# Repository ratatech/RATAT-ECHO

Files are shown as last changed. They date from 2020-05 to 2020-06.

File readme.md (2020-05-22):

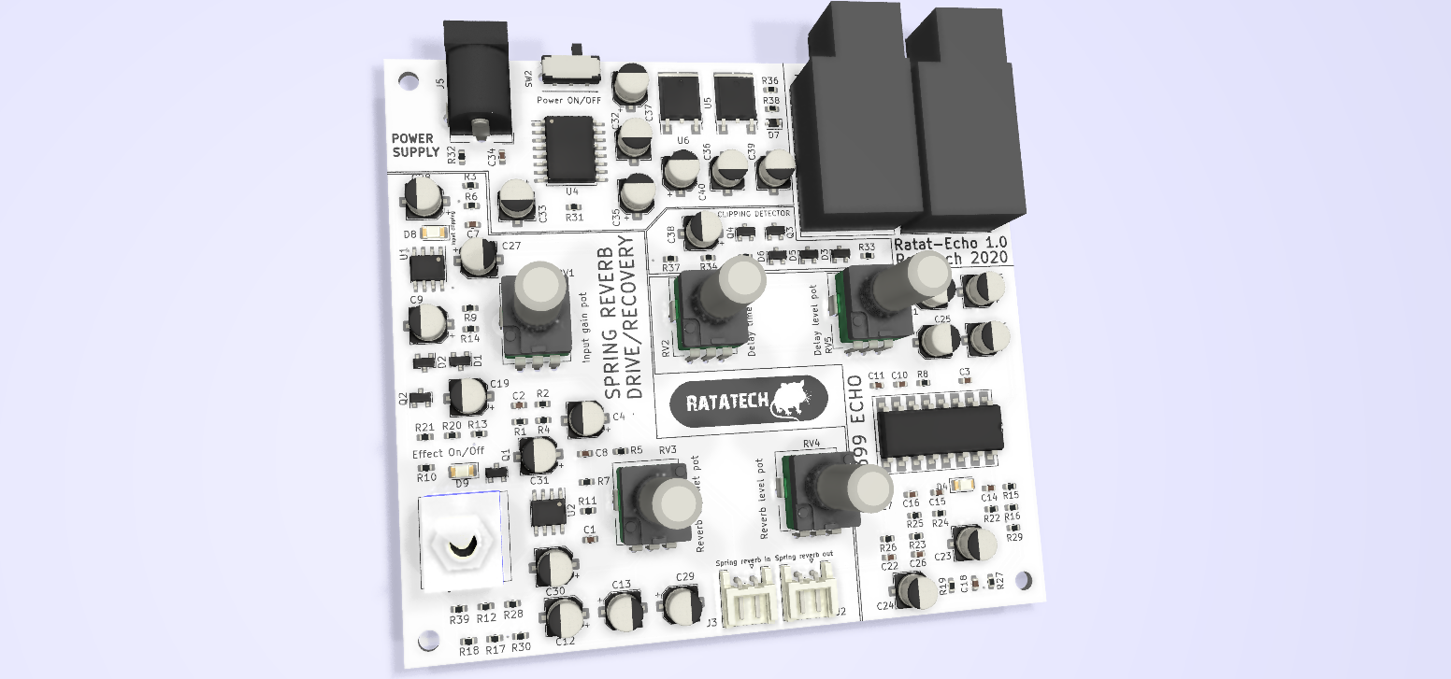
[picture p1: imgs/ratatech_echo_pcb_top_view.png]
RATAT-ECHO pcb top view


# RATAT-ECHO

This repository contains mainly the PCB design files for a small echo effect unit. The circuit it's mainly composed by two major blocks, the echo and the spring reverb drive/recovery circuits. 

The echo module is basically an adaptation of the echo circuit included in PT2399 echo processor [datasheet](./datasheets/PT2399_1.pdf). The changes were mostly a few components values to a more standarized ones and the resistor/potentiometer to reduce a bit the minimum delay time. A great analysis of this circuit is done by [Electrosmash](https://www.electrosmash.com/pt2399-analysis). 

The core of the reverb unit is the [ Accutronics, AMC2BF, 2-Spring reverb tank](https://www.amplifiedparts.com/products/reverb-tank-accutronics-amc2bf-2-spring). This is a small and very affordable($9) spring reverb tank. I liked, not only for the budget but also because of the size and the ability to fit the whole tank within the unit box. The drive and recovery circuit was taken from Rod Eliott's design ["Spring Reverb Unit for Guitar"](https://sound-au.com/project34.htm). I added an additional potentiometer a the drive input in order to have some extra input gain. Also a clipping detector was included to have some feedback when pushing too much the input gain. 

## Files

* [datasheets](./datasheets) 	Datasheets of some of the components and schematics used in this project.
* [freecad](./freecad) 			Front panel 3d model design.
* [imgs](./imgs) 				Images used in the design and captures or the 3d models/final pcb.
* [kicad](./kicad) 				Main Kicad project directory. Including schematics and pcb.
* [others](./others) 			Random stuff.

---

## License



- **[MIT license](http://opensource.org/licenses/mit-license.php)**

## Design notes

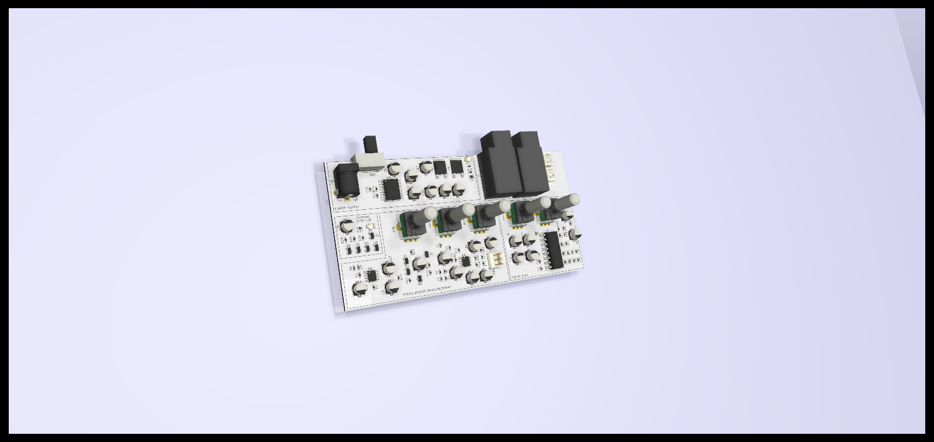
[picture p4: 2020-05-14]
kicad/ratatech_echo/ratatech_echo.png

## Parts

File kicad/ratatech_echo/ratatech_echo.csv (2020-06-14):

Reference | Quantity | Value | Footprint | Datasheet | Mouser Part Number
C10 C11 C3 C17 C16 | 5 | 0.1uF | Capacitor_SMD:C_0603_1608Metric | ~ | 710-885012206071
C15 C14 | 2 | 560pF | Capacitor_SMD:C_0603_1608Metric | ~ | 80-C0603C561G8HACTU
C18 C26 | 2 | 3.9nF | Capacitor_SMD:C_0603_1608Metric | ~ | 603-C0603KRX7R9BB392
C19 C33 C9 C4 C12 C29 C13 C23 C25 C38 | 10 | 10uF | Capacitor_SMD:CP_Elec_5x5.3 | ~ | 598-AVE106M35C12T-F
C2 | 1 | 10n | Capacitor_SMD:C_0603_1608Metric | ~ | 710-885012206040
C21 C24 | 2 | 4.7uF | Capacitor_SMD:CP_Elec_5x5.3 | ~ | 647-UWT1H4R7MCL1B
C22 | 1 | 0.01uF | Capacitor_SMD:C_0603_1608Metric | ~ | 710-885012206040
C27 C28 C35 C30 C31 C5 | 6 | 100uF | Capacitor_SMD:CP_Elec_5x5.3 | ~ | 661-EMZJ6R3A101ME61G
C32 C36 C37 | 3 | 2uF | Capacitor_SMD:CP_Elec_5x5.3 | ~ | 661-EMVE630ADA3R3ME5
C34 | 1 | 0.002uF | Capacitor_SMD:C_0603_1608Metric | ~ | 603-CC603KRX7R9BB202
C39 C40 | 2 | 1uF | Capacitor_SMD:CP_Elec_5x5.3 | ~ | RVS-50V010MU-R
C6 | 1 | 47uF | Capacitor_SMD:CP_Elec_5x5.3 | ~ | 140-VE470M1CTR0505
C7 C1 | 2 | 100n | Capacitor_SMD:C_0603_1608Metric | ~ | 710-885012206071
C8 | 1 | 470pF | Capacitor_SMD:C_0603_1608Metric | ~ | 710-885012206081
D2 D1 D5 D6 D3 | 5 | D | Diode_SMD:D_SOT-23_ANK | ~ | 621-MMBD4148-F
D4 D8 D9 | 3 | LED | LED_SMD:LED_1206_3216Metric | ~ | 327-BR1101WTR
D7 | 1 | D_Zener_5.6v | Diode_SMD:D_SOD-323 | ~ | 863-SZMM3Z6V8ST1G
H1 H3 H2 H4 | 4 | MountingHole | MountingHole:MountingHole_3mm | ~
J1 J4 | 2 | AudioJack2 | Connector_Audio:Jack_6.35mm_Neutrik_NRJ4HF-1_Horizontal | ~ | 550-10284G
J3 J2 | 2 | Conn_01x02 | Connector_JST:JST_EH_S2B-EH_1x02_P2.50mm_Horizontal | ~ | 474-PRT-09749
J5 | 1 | Barrel_Jack_Switch | Connector_BarrelJack:BarrelJack_CUI_PJ-102AH_Horizontal | ~ | 490-PJ-102BH
Q1 Q3 | 2 | 2N3904 | Package_TO_SOT_SMD:SOT-23 | https://www.fairchildsemi.com/datasheets/2N/2N3904.pdf | 771-MMBT3904T/R
Q2 Q4 | 2 | 2N3906 | Package_TO_SOT_SMD:SOT-23 | https://www.fairchildsemi.com/datasheets/2N/2N3906.pdf | 771-MMBT3906T/R
R1 R22 | 2 | 4.7K | Resistor_SMD:R_0603_1608Metric | ~ | 71-CRCW06034K70JNEAC
R10 | 1 | 3.3K | Resistor_SMD:R_0603_1608Metric | ~ | 71-CRCW06033K30FKEAC
R13 R14 | 2 | 3.9K | Resistor_SMD:R_0603_1608Metric | ~ | 652-CR0603-FX3901ELF
R17 R18 R28 R15 R16 R29 R24 R25 R33 R35 | 10 | 10K | Resistor_SMD:R_0603_1608Metric | ~ | 755-SFR03EZPF1002
R19 R23 | 2 | 15K | Resistor_SMD:R_0603_1608Metric | ~ | 603-RC0603FR-0715KL
R2 | 1 | 220K | Resistor_SMD:R_0603_1608Metric | ~ | 603-RC0603FR-10220KL
R21 R20 | 2 | 10 | Resistor_SMD:R_0603_1608Metric | ~ | 71-CRCW060310R0FKEAC
R26 | 1 | 5.6K | Resistor_SMD:R_0603_1608Metric | ~ | 652-CR0603JW-562ELF
R3 R27 R34 | 3 | 100K | Resistor_SMD:R_0603_1608Metric | ~ | 71-CRCW0603100KFKEAC
R30 | 1 | 100 | Resistor_SMD:R_0603_1608Metric | ~ | 71-CRCW0603100RFKEAC
R32 | 1 | 240K | Resistor_SMD:R_0603_1608Metric | ~ | 652-CR0603FX-2403ELF
R36 R39 | 2 | 470 | Resistor_SMD:R_0603_1608Metric | ~ | 71-CRCW0603470RFKEAC
R37 | 1 | 1K | Resistor_SMD:R_0603_1608Metric | ~ | 71-CRCW06031K00FKEAC
R38 | 1 | 270 | Resistor_SMD:R_0603_1608Metric | ~ | 652-CR0603FX-2700ELF
R4 | 1 | 220 | Resistor_SMD:R_0603_1608Metric | ~ | 71-CRCW0603220RFKEAC
R5 R11 | 2 | 560 | Resistor_SMD:R_0603_1608Metric | ~ | 71-CRCW0603560RFKEAC
R6 R31 R7 R12 | 4 | 22K | Resistor_SMD:R_0603_1608Metric | ~ | 71-CRCW060322K0FKEAC
R8 | 1 | 680 | Resistor_SMD:R_0603_1608Metric | ~ | 71-CRCW0603680RJNEAC
R9 | 1 | 150 | Resistor_SMD:R_0603_1608Metric | ~ | 71-CRCW0603150RJNEAC
RV1 | 1 | 100K | Potentiometer_THT:Potentiometer_Alps_RK09K_Single_Vertical | ~ | 652-PTV09A4025FB104
RV2 | 1 | 22K | Potentiometer_THT:Potentiometer_Alps_RK09K_Single_Vertical | ~ | 652-PTV09A-4030UB203
RV4 RV3 | 2 | 10K | Potentiometer_THT:Potentiometer_Alps_RK09K_Single_Vertical | ~ | 652-PTV09A-4025FB103
RV5 | 1 | 50K | Potentiometer_THT:Potentiometer_Alps_RK09K_Single_Vertical | ~ | 652-PTV09A-4225FA503
SW1 | 1 | SW_DPDT_x2 | M2028B2B1W03:M2028B2B1W03 |  | 612-100DP3T4B1M1Q
SW2 | 1 | SW_SPST | Button_Switch_THT:SW_CuK_OS102011MA1QN1_SPDT_Angled | ~ | 611-OS102011MA1QN1
U1 U2 | 2 | NE5532 | Package_SO:SOIC-8_3.9x4.9mm_P1.27mm | http://www.ti.com/lit/ds/symlink/ne5532.pdf | 595-NE5532DR
U3 | 1 | PT2399 | Package_DIP:DIP-16_W8.89mm_SMDSocket_LongPads | http://sound.westhost.com/pt2399.pdf | 200-ICF308TO
U4 | 1 | LT1054xSOIC16 | Package_SO:SOIC-16W_7.5x10.3mm_P1.27mm |  | 595-LT1054CDWR
U5 | 1 | LM7812_TO220 | Package_TO_SOT_SMD:ATPAK-2 | http://www.fairchildsemi.com/ds/LM/LM7805.pdf | 511-L78M12CDT-TR
U6 | 1 | LM7912_TO220 | Package_TO_SOT_SMD:ATPAK-2 | http://www.fairchildsemi.com/ds/LM/LM7905.pdf | 512-KA79M12RTF
U7 | 1 | logo | imgs:ratatech_bitmap

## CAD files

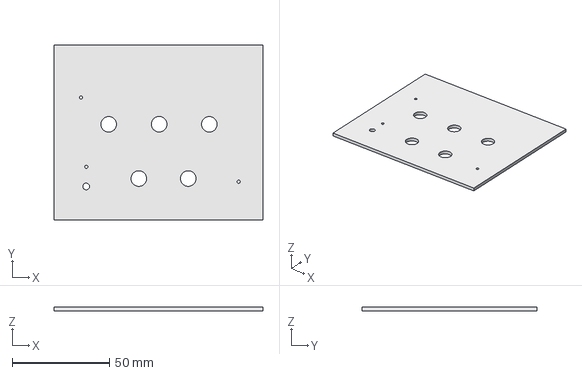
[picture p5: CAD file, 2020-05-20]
freecad/front_panel_export.FCStd
107.4 x 90.0 x 2.00 mm

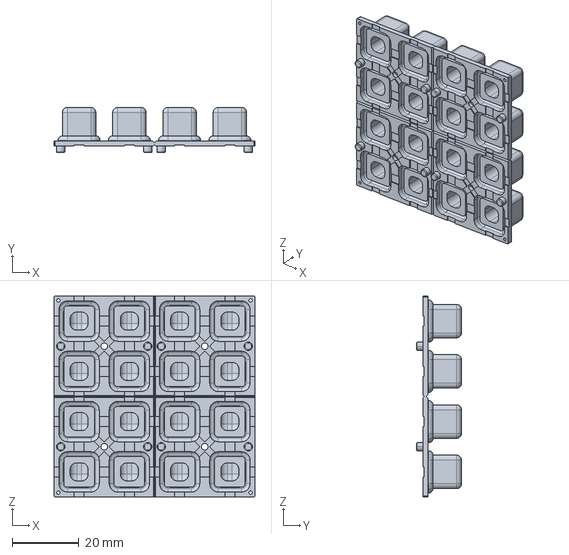
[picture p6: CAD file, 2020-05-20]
others/Adafruit_Trellis-master/Adafruit Trellis 3mm.stp
60.0 x 13.5 x 60.0 mm

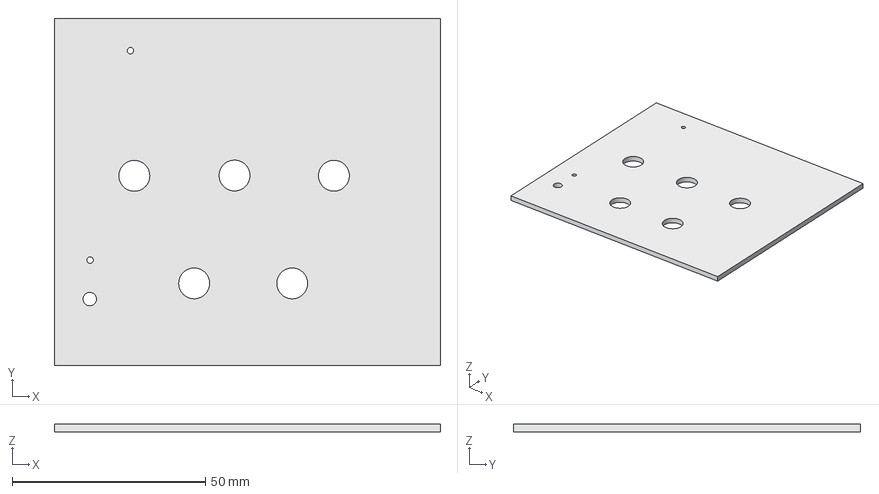
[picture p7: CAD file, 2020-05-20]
freecad/front_panel_2.FCStd
100.0 x 90.0 x 2.00 mm

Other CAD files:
freecad/front_panel.FCStd
others/Adafruit_Trellis-master/Adafruit Trellis 3mm.stl

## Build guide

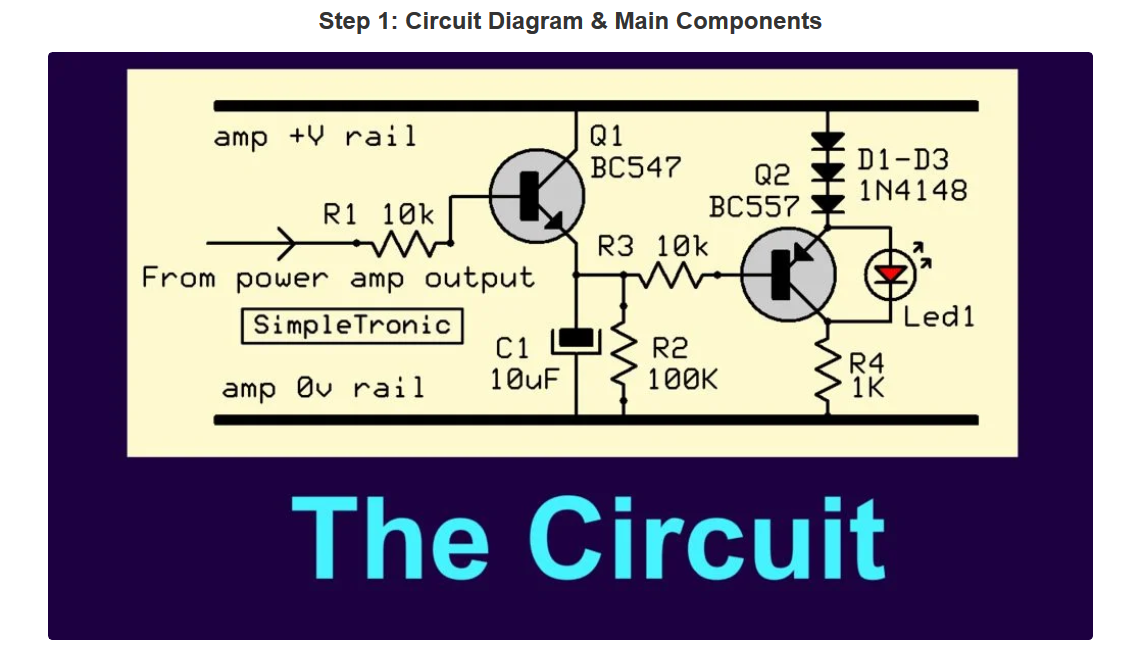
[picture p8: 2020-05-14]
datasheets/Clip Indicator (LED) for Any Power Amp _ 6 Steps (with Pictures) - Instructables.png

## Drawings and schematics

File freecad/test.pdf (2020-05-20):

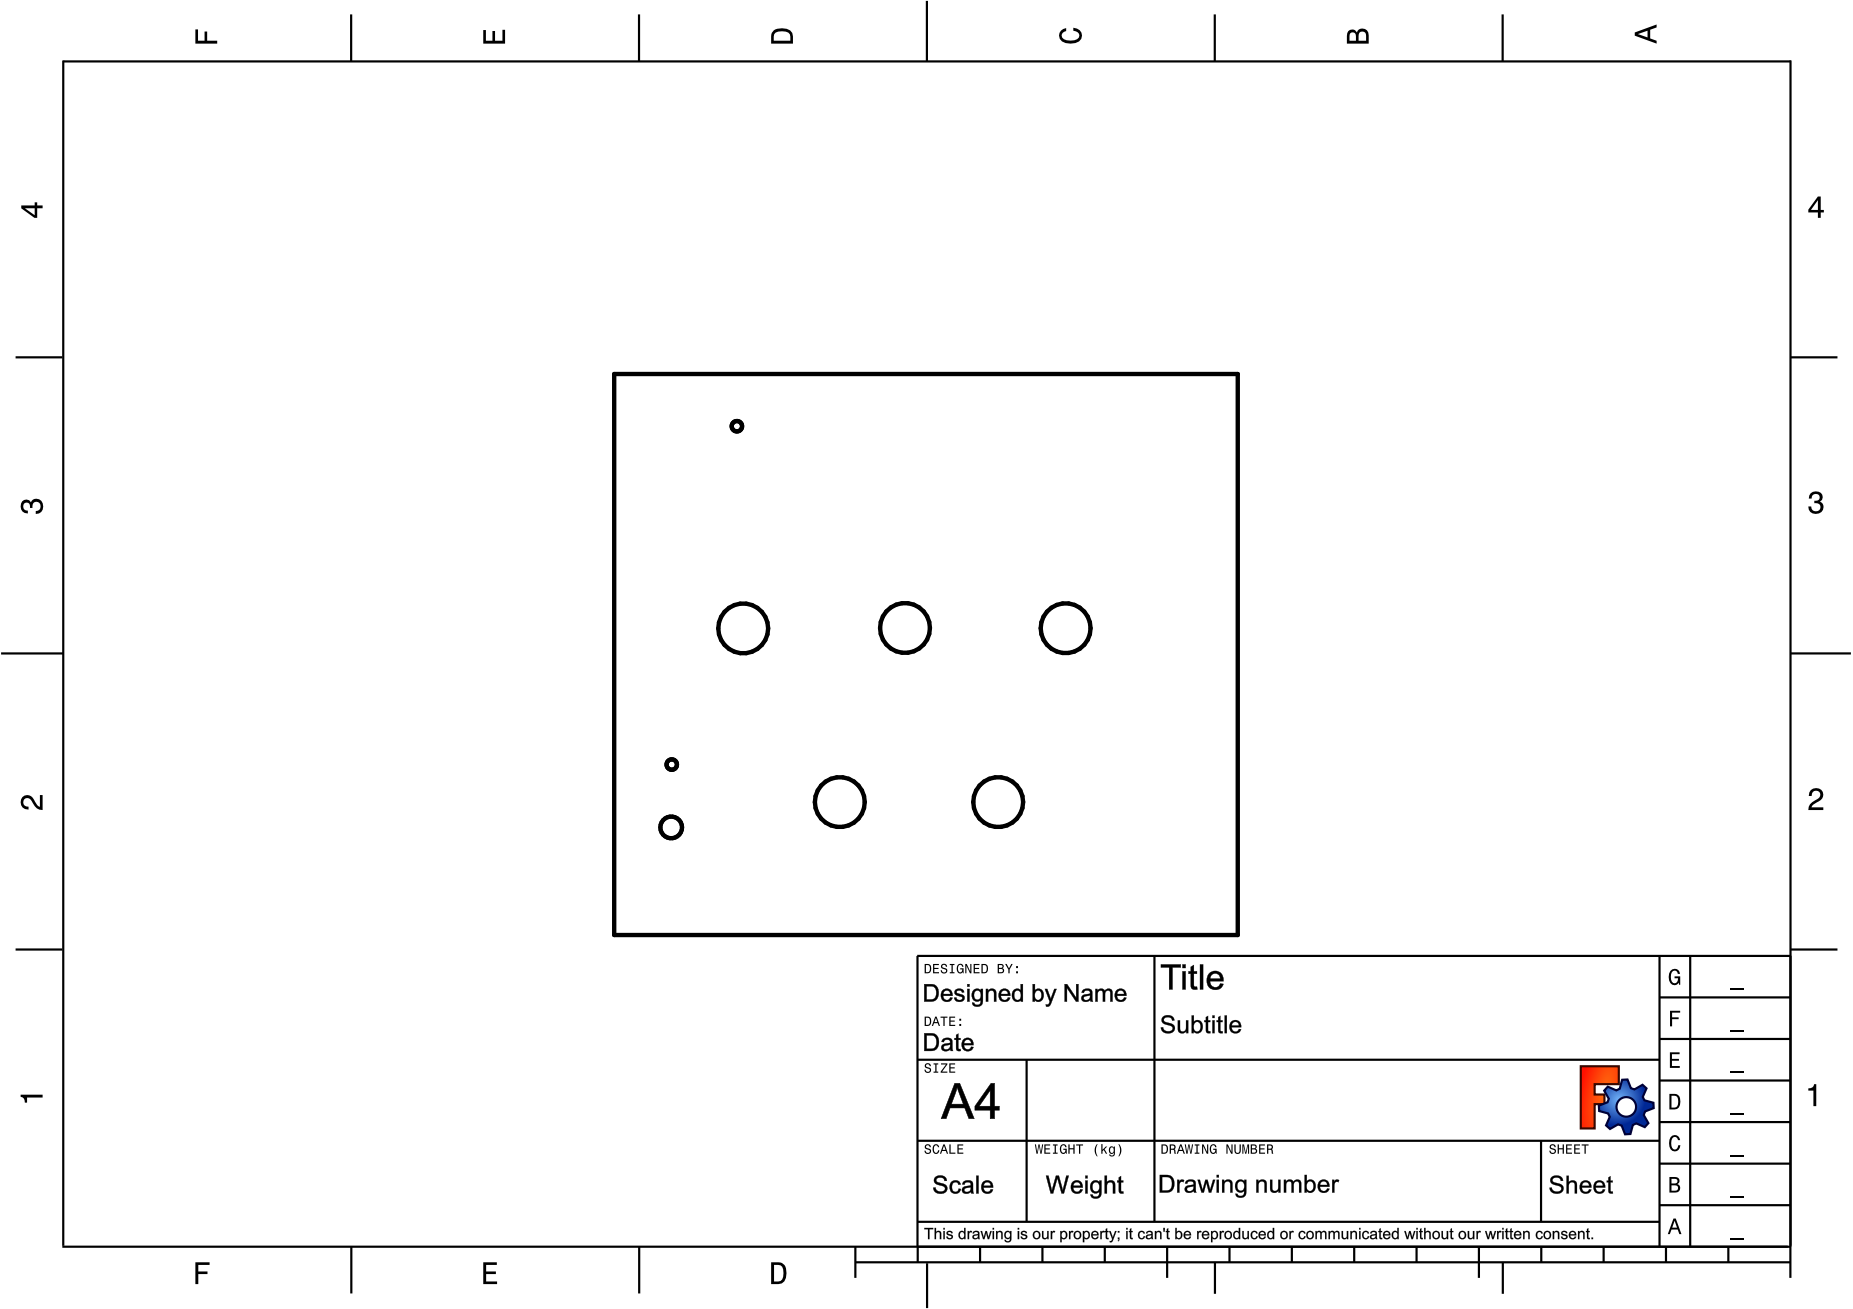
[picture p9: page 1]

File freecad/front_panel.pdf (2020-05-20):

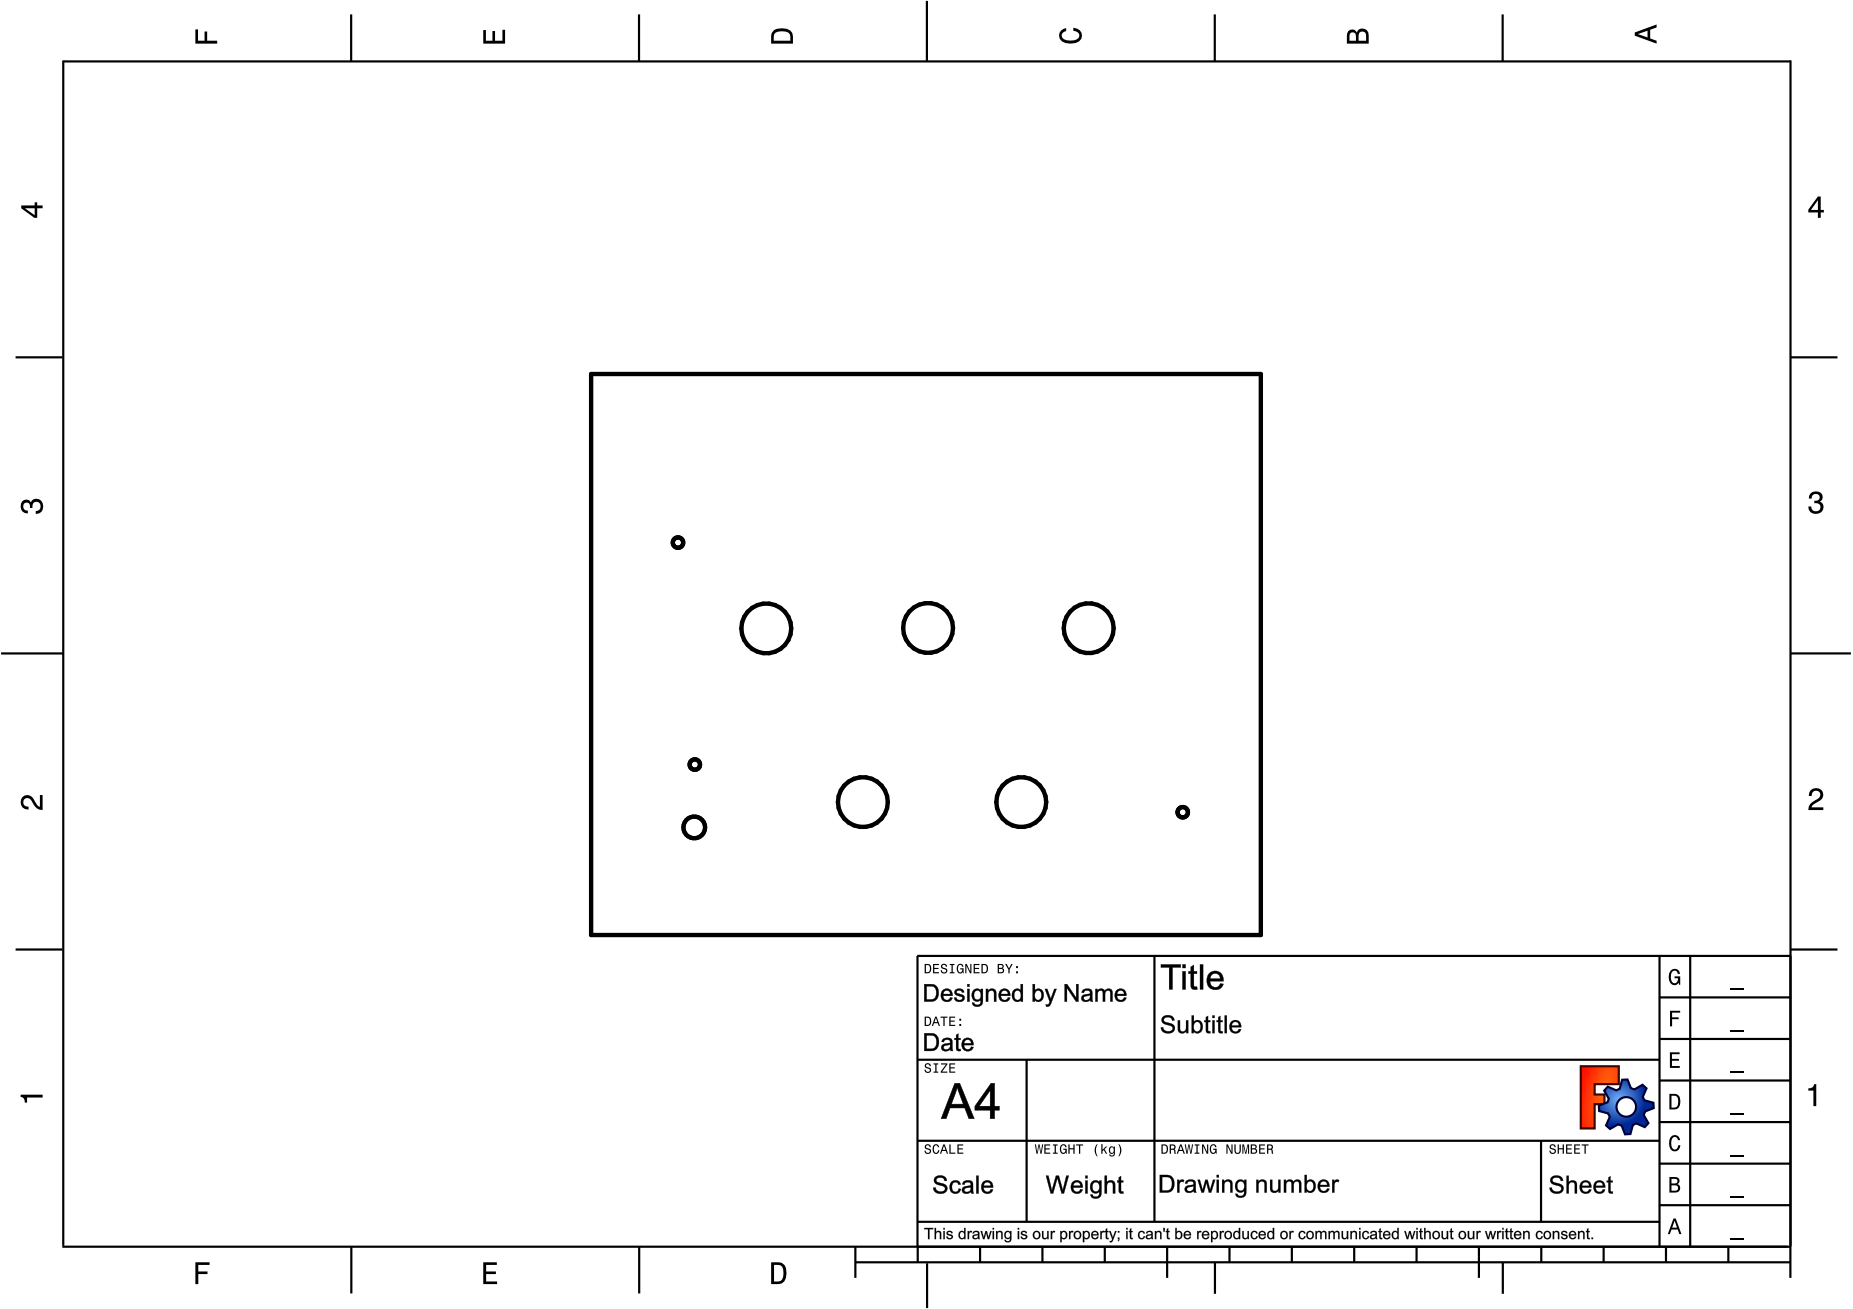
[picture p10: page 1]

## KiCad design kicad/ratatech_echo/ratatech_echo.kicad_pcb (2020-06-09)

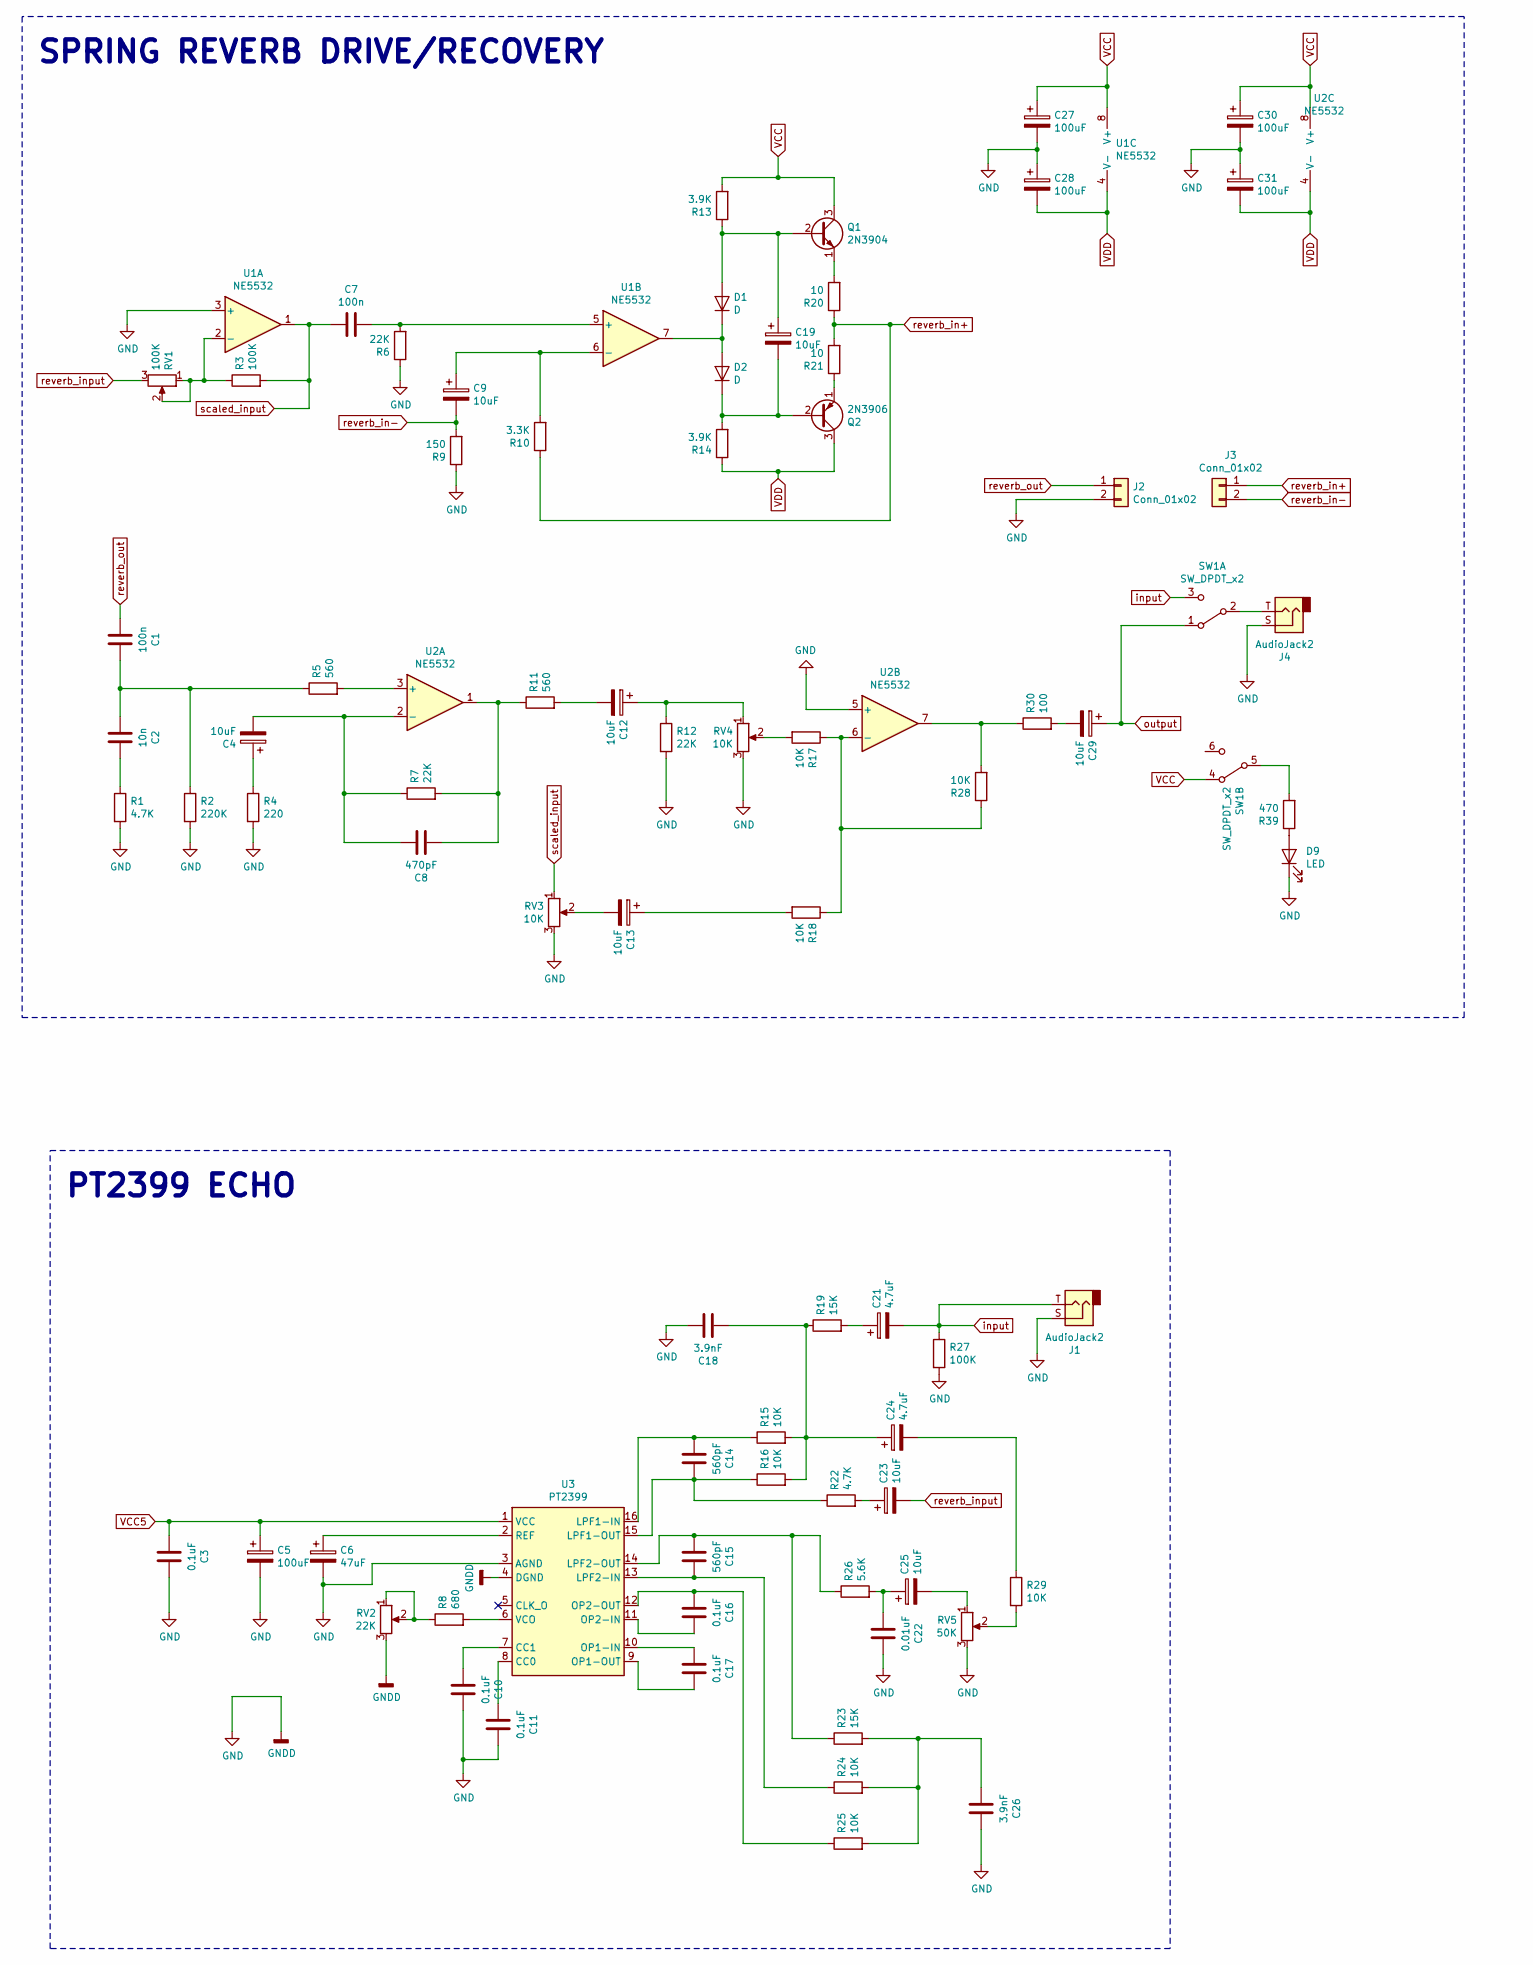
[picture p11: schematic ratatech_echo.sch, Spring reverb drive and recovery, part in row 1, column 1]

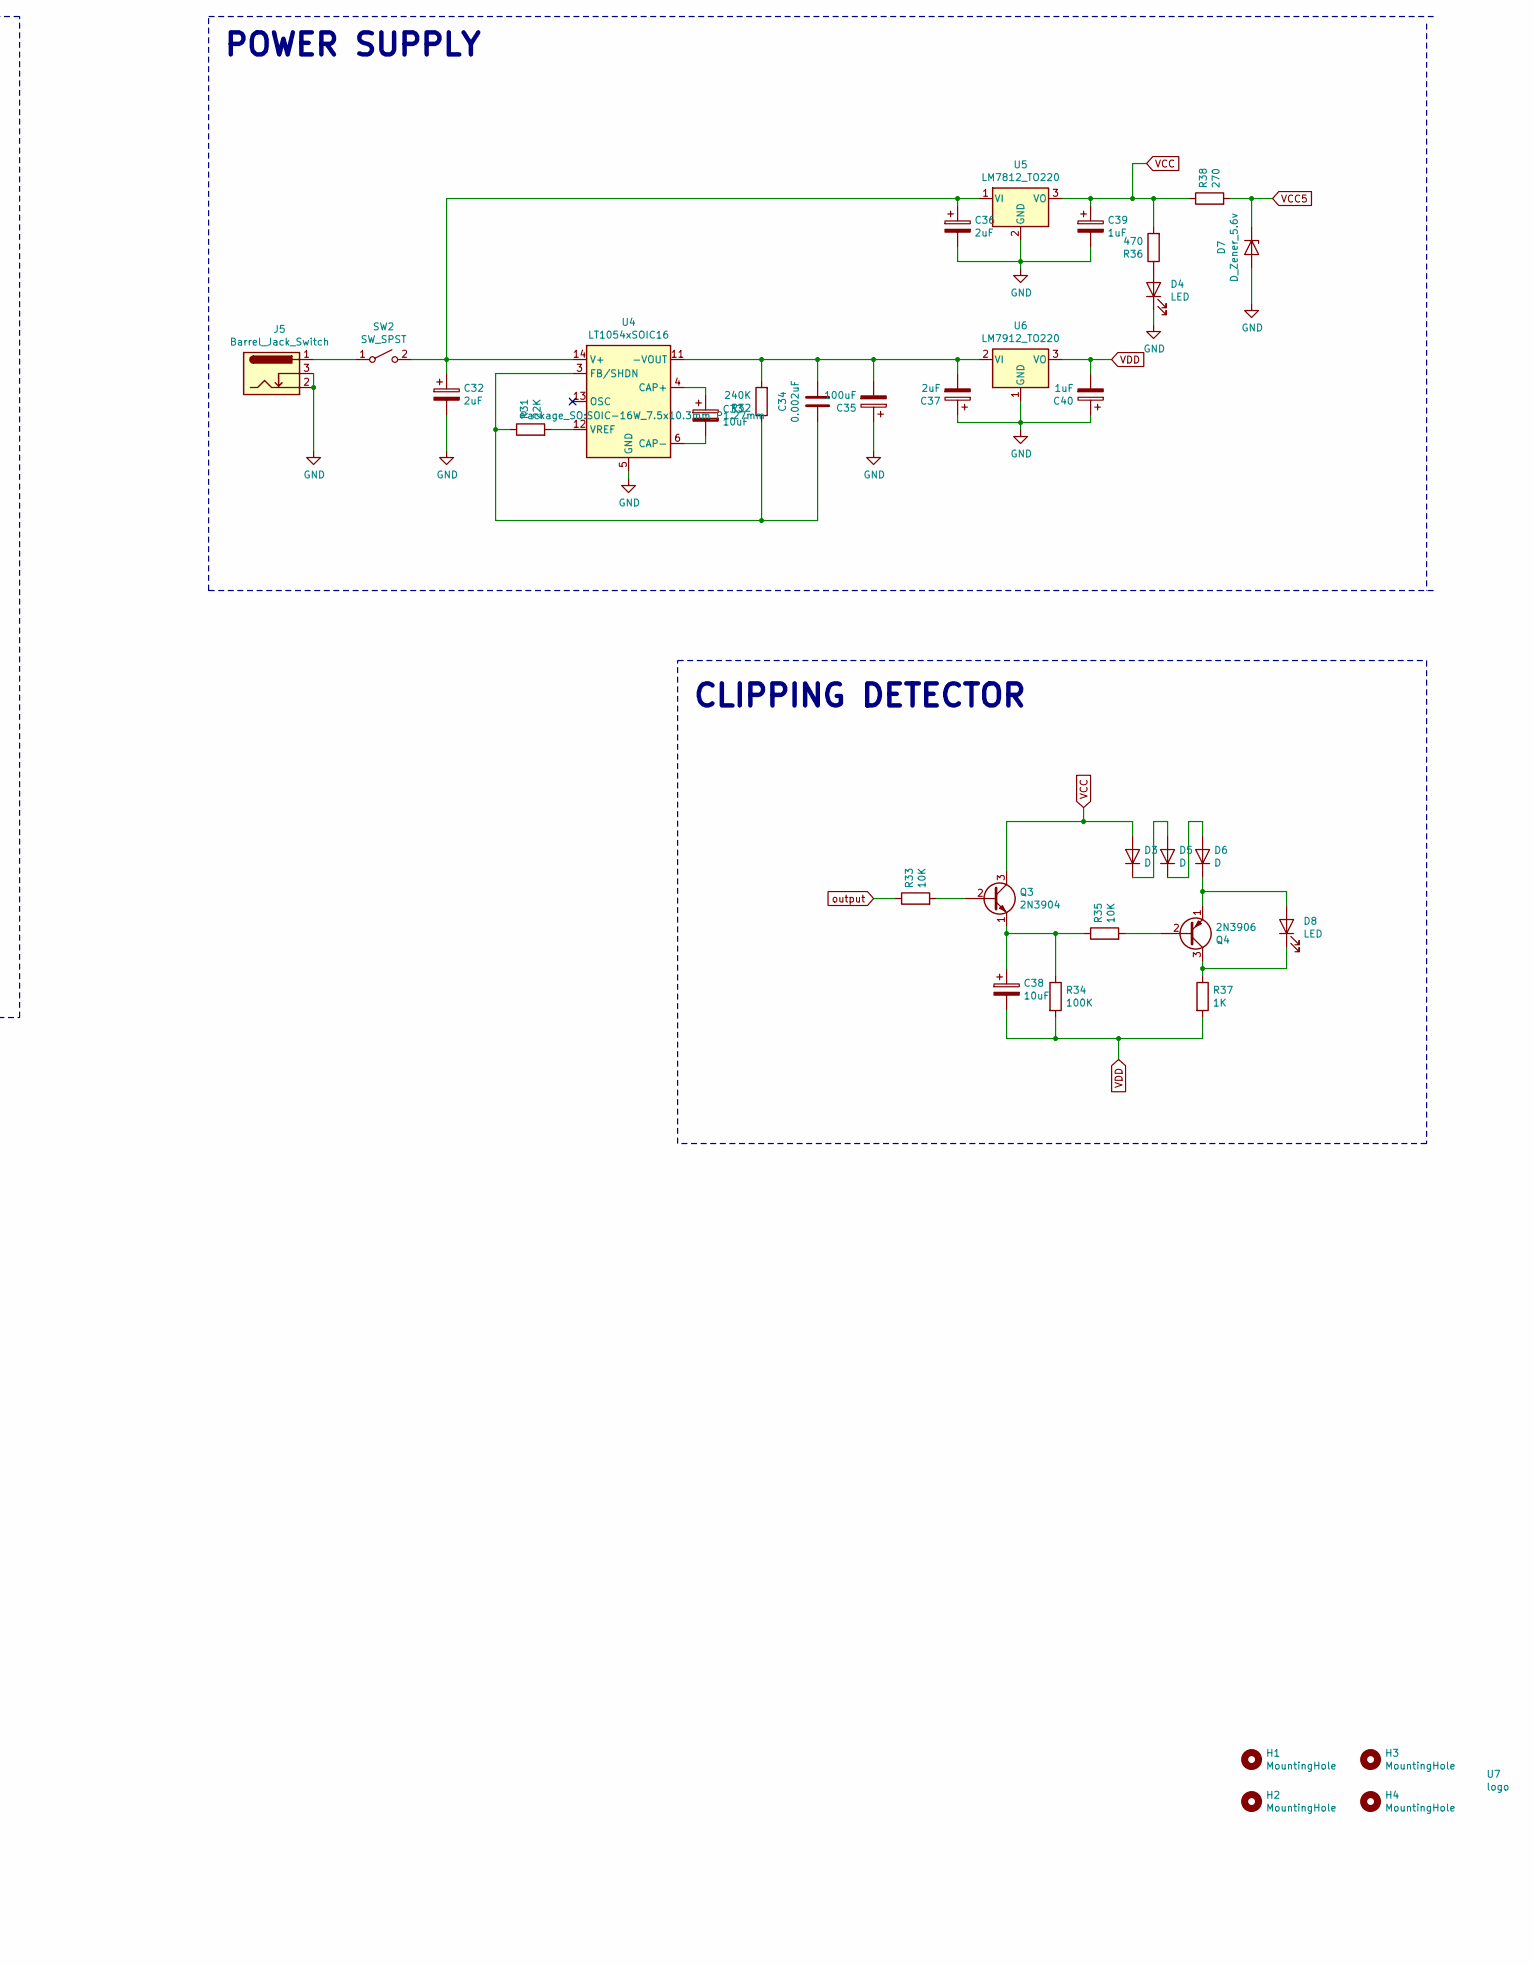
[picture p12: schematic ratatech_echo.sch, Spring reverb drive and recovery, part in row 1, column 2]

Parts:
C1, C7: 100n; C_0603_1608Metric
C2: 10n; C_0603_1608Metric
C3, C10, C11, C16, C17: 0.1uF; C_0603_1608Metric
C4, C9, C12, C13, C19, C23, C25, C29, C33, C38: 10uF; CP_Elec_5x5.3
C5, C27, C28, C30, C31, C35: 100uF; CP_Elec_5x5.3
C6: 47uF; CP_Elec_5x5.3
C8: 470pF; C_0603_1608Metric
C14, C15: 560pF; C_0603_1608Metric
C18, C26: 3.9nF; C_0603_1608Metric
C21, C24: 4.7uF; CP_Elec_5x5.3
C22: 0.01uF; C_0603_1608Metric
C32, C36, C37: 2uF; CP_Elec_5x5.3
C34: 0.002uF; C_0603_1608Metric
C39, C40: 1uF; CP_Elec_5x5.3
D1, D2, D3, D5, D6: D; D_SOT-23_ANK
D4, D8, D9: LED; LED_1206_3216Metric
D7: D_Zener_5.6v; D_SOD-323
H1, H2, H3, H4: MountingHole; MountingHole_3mm
J1, J4: AudioJack2; Jack_6.35mm_Neutrik_NRJ4HF-1_Horizontal
J2, J3: Conn_01x02; JST_EH_S2B-EH_1x02_P2.50mm_Horizontal
J5: Barrel_Jack_Switch; BarrelJack_CUI_PJ-102AH_Horizontal
Q1, Q3: 2N3904; SOT-23
Q2, Q4: 2N3906; SOT-23
R1, R22: 4.7K; R_0603_1608Metric
R2: 220K; R_0603_1608Metric
R3, R27, R34: 100K; R_0603_1608Metric
R4: 220; R_0603_1608Metric
R5, R11: 560; R_0603_1608Metric
R6, R7, R12, R31: 22K; R_0603_1608Metric
R8: 680; R_0603_1608Metric
R9: 150; R_0603_1608Metric
R10: 3.3K; R_0603_1608Metric
R13, R14: 3.9K; R_0603_1608Metric
R15, R16, R17, R18, R24, R25, R28, R29, R33, R35: 10K; R_0603_1608Metric
R19, R23: 15K; R_0603_1608Metric
R20, R21: 10; R_0603_1608Metric
R26: 5.6K; R_0603_1608Metric
R30: 100; R_0603_1608Metric
R32: 240K; R_0603_1608Metric
R36, R39: 470; R_0603_1608Metric
R37: 1K; R_0603_1608Metric
R38: 270; R_0603_1608Metric
RV1: 100K; Potentiometer_Alps_RK09K_Single_Vertical
RV2: 22K; Potentiometer_Alps_RK09K_Single_Vertical
RV3, RV4: 10K; Potentiometer_Alps_RK09K_Single_Vertical
RV5: 50K; Potentiometer_Alps_RK09K_Single_Vertical
SW1: SW_DPDT_x2; M2028B2B1W03
SW2: SW_SPST; SW_CuK_OS102011MA1QN1_SPDT_Angled
U1, U2: NE5532; SOIC-8_3.9x4.9mm_P1.27mm
U3: PT2399; DIP-16_W8.89mm_SMDSocket_LongPads
U4: LT1054xSOIC16; SOIC-16W_7.5x10.3mm_P1.27mm
U5: LM7812_TO220; ATPAK-2
U6: LM7912_TO220; ATPAK-2
U7: logo; ratatech_bitmap

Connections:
GND: C3.1, C5.2, C6.2, C10.1, C11.1, C18.1, C22.1, C26.1, C27.2, C28.1, C30.2, C31.1, C32.2, C35.1, C36.2, C37.1, C39.2, C40.1, D4.1 (K), D7.2 (A), D9.1 (K), J1.S, J2.2, J4.S, J5.2, J5.3, R1.2, R2.2, R4.2, R6.1, R9.1, R12.2, R27.2, RV2.3, RV3.3, RV4.3, RV5.3, U1.3 (+), U2.5 (+), U3.3 (AGND), U3.4 (DGND), U4.5 (GND), U5.2 (GND), U6.1 (GND)
unnamed: C1.1, C2.2, R2.1, R5.1
unnamed: C2.1, R1.1
unnamed: C4.1, R4.1
unnamed: C4.2, C8.1, R7.1, U2.2 (-)
unnamed: C6.1, U3.2 (REF)
unnamed: C7.1, R6.2, U1.5 (+)
unnamed: C8.2, R7.2, R11.1, U2.1
unnamed: C9.1, R10.2, U1.6 (-)
unnamed: C10.2, U3.7 (CC1)
unnamed: C11.2, U3.8 (CC0)
unnamed: C12.1, R12.1, RV4.1
unnamed: C12.2, R11.2
unnamed: C13.1, R18.2
unnamed: C13.2, RV3.2
unnamed: C14.1, R16.1, R22.1, U3.15 (LPF1-OUT)
unnamed: C14.2, R15.1, U3.16 (LPF1-IN)
unnamed: C15.1, R24.1, U3.13 (LPF2-IN)
unnamed: C15.2, R23.1, R26.1, U3.14 (LPF2-OUT)
unnamed: C16.1, U3.11 (OP2-IN)
unnamed: C16.2, R25.1, U3.12 (OP2-OUT)
unnamed: C17.1, U3.9 (OP1-OUT)
unnamed: C17.2, U3.10 (OP1-IN)
unnamed: C18.2, C24.1, R15.2, R16.2, R19.1
unnamed: C19.1, D1.2 (A), Q1.2 (B), R13.1
unnamed: C19.2, D2.1 (K), Q2.2 (B), R14.2
unnamed: C21.1, R19.2
unnamed: C22.2, C25.1, R26.2
unnamed: C23.1, R22.2
unnamed: C24.2, R29.1
unnamed: C25.2, RV5.1
unnamed: C26.2, R23.2, R24.2, R25.2
unnamed: C29.2, R30.2
unnamed: C32.1, C36.1, SW2.2 (B), U4.14 (V+), U5.1 (VI)
unnamed: C33.1, U4.4 (CAP+)
unnamed: C33.2, U4.6 (CAP-)
unnamed: C34.1, C35.2, C37.2, R32.2, U4.11 (-VOUT), U6.2 (VI)
unnamed: C34.2, R31.1, R32.1, U4.3 (FB/SHDN)
unnamed: C38.1, Q3.1 (E), R34.1, R35.1
unnamed: D1.1 (K), D2.2 (A), U1.7
unnamed: D3.1 (K), D5.2 (A)
unnamed: D4.2 (A), R36.1
unnamed: D5.1 (K), D6.2 (A)
unnamed: D6.1 (K), D8.2 (A), Q4.1 (E)
unnamed: D8.1 (K), Q4.3 (C), R37.1
unnamed: D9.2 (A), R39.1
unnamed: J4.T, SW1.2 (B)
unnamed: J5.1, SW2.1 (A)
unnamed: Q1.1 (E), R20.2
unnamed: Q2.1 (E), R21.1
unnamed: Q3.2 (B), R33.2
unnamed: Q4.2 (B), R35.2
unnamed: R3.1, RV1.1, RV1.2, U1.2 (-)
unnamed: R5.2, U2.3 (+)
unnamed: R8.1, RV2.1, RV2.2
unnamed: R8.2, U3.6 (VCO)
unnamed: R17.1, R18.1, R28.1, U2.6 (-)
unnamed: R17.2, RV4.2
unnamed: R28.2, R30.1, U2.7
unnamed: R29.2, RV5.2
unnamed: R31.2, U4.12 (VREF)
unnamed: R39.2, SW1.5 (B)
VCC: C27.1, C30.1, C39.1, D3.2 (A), Q1.3 (C), Q3.3 (C), R13.2, R36.2, R38.1, SW1.4 (A), U1.8 (V+), U2.8 (V+), U5.3 (VO)
VCC5: C3.2, C5.1, D7.1 (K), R38.2, U3.1 (VCC)
VDD: C28.2, C31.2, C38.2, C40.2, Q2.3 (C), R14.1, R34.2, R37.2, U1.4 (V-), U2.4 (V-), U6.3 (VO)
input: C21.2, J1.T, R27.1, SW1.3 (C)
output: C29.1, R33.1, SW1.1 (A)
reverb_in+: J3.1, R10.1, R20.1, R21.2
reverb_in-: C9.2, J3.2, R9.2
reverb_input: C23.2, RV1.3
reverb_out: C1.2, J2.1
scaled_input: C7.2, R3.2, RV3.1, U1.1

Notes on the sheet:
CLIPPING DETECTOR
PT2399 ECHO
SPRING REVERB DRIVE/RECOVERY
POWER SUPPLY

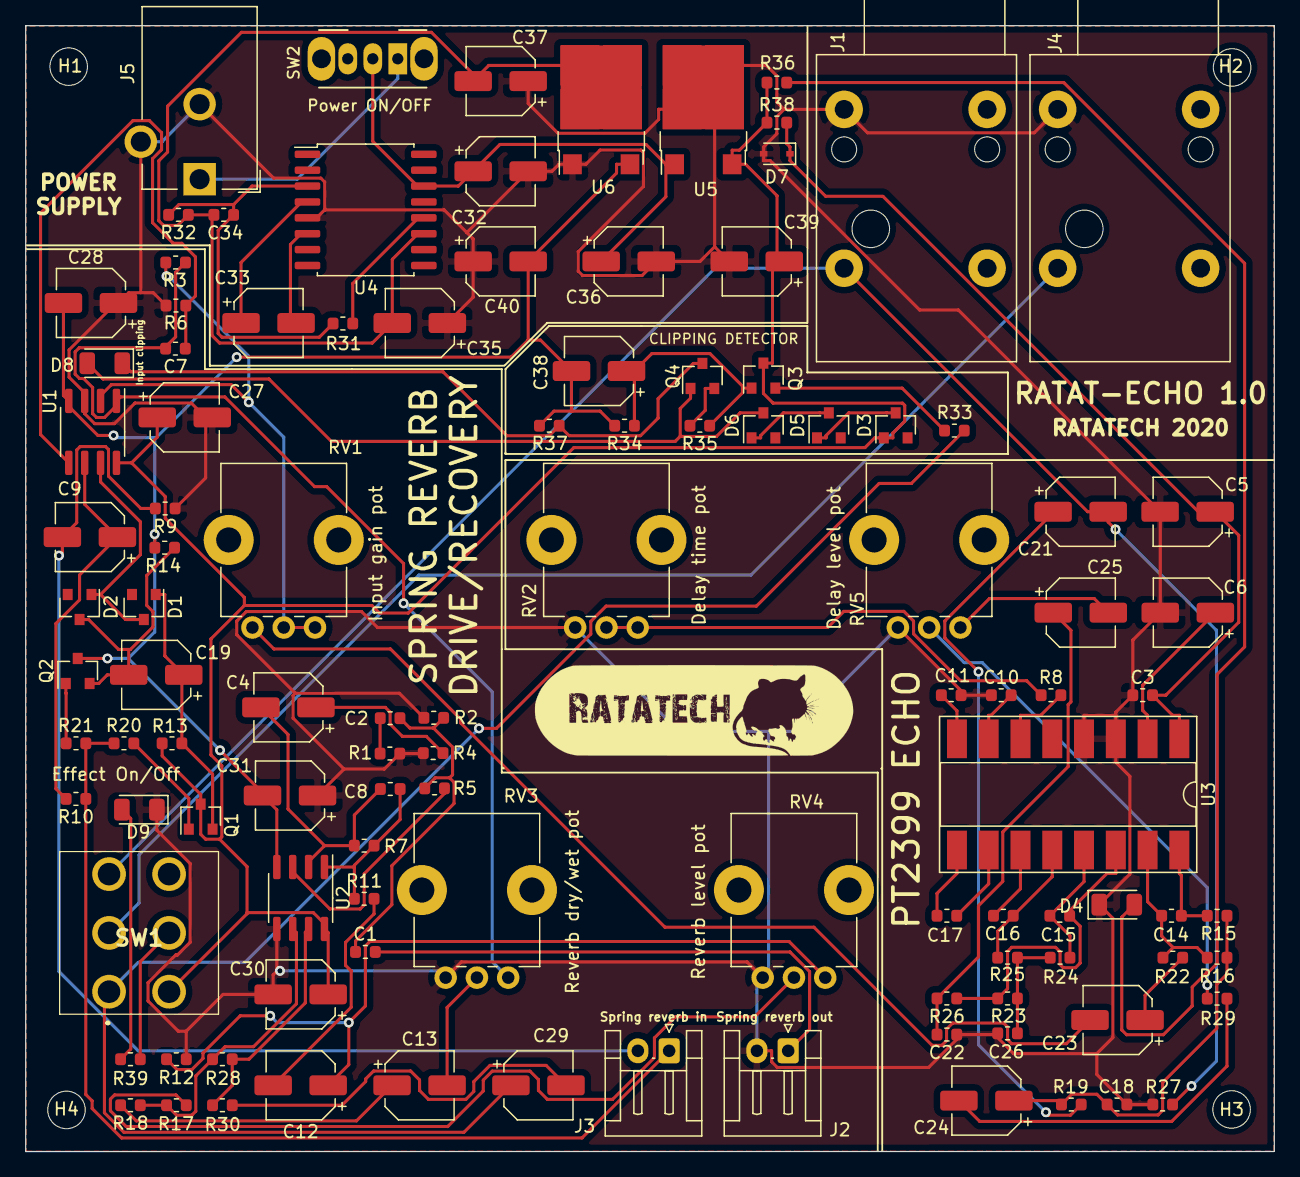
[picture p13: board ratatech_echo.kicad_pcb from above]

Board: 2 copper layers, 99.8 x 90.0 mm, 114 parts (0 on the bottom side), 72 nets.

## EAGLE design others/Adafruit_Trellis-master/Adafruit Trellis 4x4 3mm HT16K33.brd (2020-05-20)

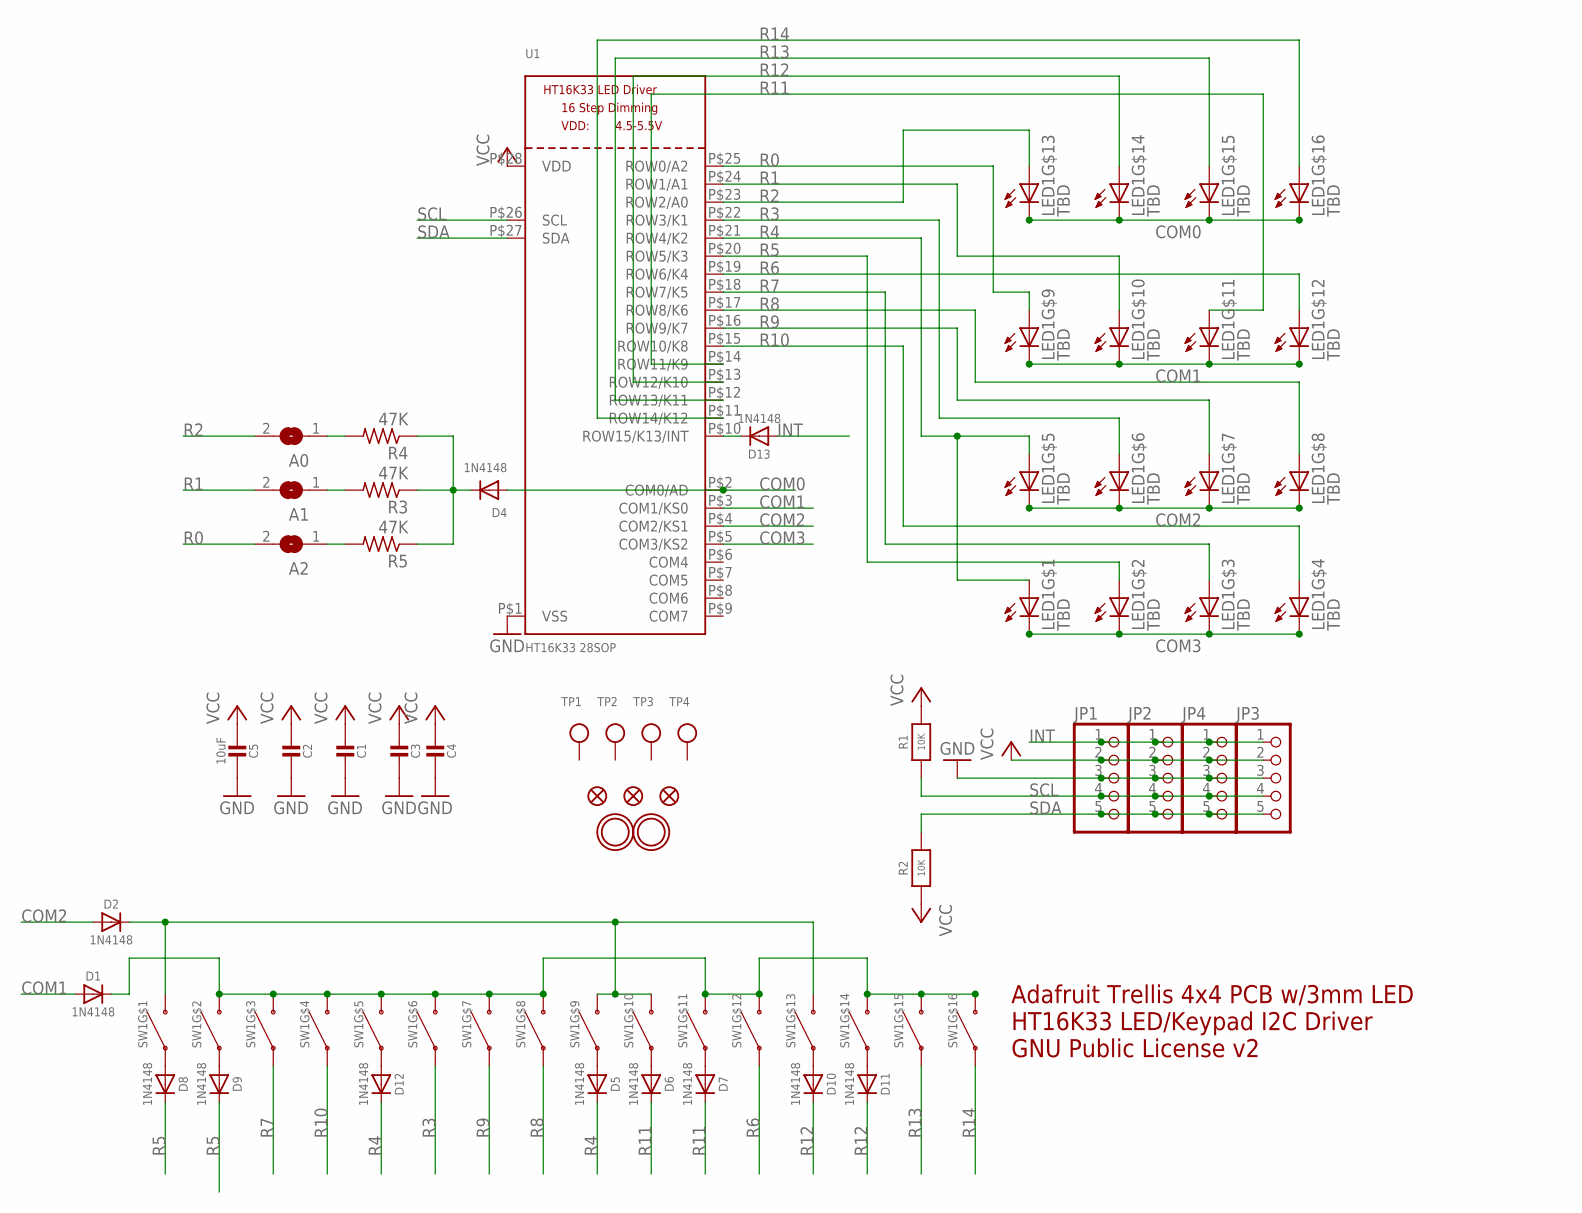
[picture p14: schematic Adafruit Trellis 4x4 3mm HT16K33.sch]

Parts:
A0, A1, A2: SOLDERJUMPERREFLOW_NOPASTE; SOLDERJUMPER_REFLOW_NOPASTE
C1, C2, C3, C4: CAP_CERAMIC_0805; _0805
C5: 10uF; _0805
D1, D2, D5, D6, D7, D8, D9, D10, D11, D12, D13: 1N4148; SOD-323
D4: 1N4148; SOD-323F
FID1, FID2, FID3: FIDUCIAL""; FIDUCIAL_1MM
JP1, JP2, JP3, JP4: HEADER-1X5EDGESMT; 1X5_SMT
LED1: TBD; LED3MM-4X4GRID
R1, R2: 10K; _0805
R3, R4, R5: 47K; R0805
SW1: SWITCH-SILICON-4X4GRID-10MM-5.4MM; ELAST_PAD_SQUARE_10MM_5.4MM_4X4GRID
TP1, TP2, TP3, TP4: TESTPOINT; TESTPOINT_SMT
U1: HT16K33 28SOP; SOP28_300MIL
U$1, U$2: MOUNTINGHOLE2.5; MOUNTINGHOLE_2.5_PLATED

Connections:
COM0: D4.A, LED1.K13 (C), LED1.K14 (C), LED1.K15 (C), LED1.K16 (C), U1.P$2 (COM0/AD)
COM1: D1.A, LED1.K9 (C), LED1.K10 (C), LED1.K11 (C), LED1.K12 (C), U1.P$3 (COM1/KS0)
COM2: D2.A, LED1.K5 (C), LED1.K6 (C), LED1.K7 (C), LED1.K8 (C), U1.P$4 (COM2/KS1)
COM3: LED1.K1 (C), LED1.K2 (C), LED1.K3 (C), LED1.K4 (C), U1.P$5 (COM3/KS2)
GND: C1.1, C2.1, C3.1, C4.1, C5.1, JP1.3, JP2.3, JP3.3, JP4.3, U1.P$1 (VSS)
INT: D13.A, JP1.1, JP2.1, JP3.1, JP4.1
unnamed: D2.C, SW1.B1, SW1.B9, SW1.B10, SW1.B13
unnamed: D13.C, U1.P$10 (ROW15/K13/INT)
unnamed: D5.A, SW1.A9
unnamed: D6.A, SW1.A10
unnamed: D1.C, SW1.B2, SW1.B3, SW1.B4, SW1.B5, SW1.B6, SW1.B7, SW1.B8, SW1.B11, SW1.B12, SW1.B14, SW1.B15, SW1.B16
unnamed: D7.A, SW1.A11
unnamed: D8.A, SW1.A1
unnamed: D9.A, SW1.A2
unnamed: A2.1, R5.2
unnamed: D10.A, SW1.A13
unnamed: D11.A, SW1.A14
unnamed: D12.A, SW1.A5
unnamed: D4.C, R3.1, R4.1, R5.1
unnamed: A1.1, R3.2
unnamed: A0.1, R4.2
R0: A2.2, LED1.A9 (A), U1.P$25 (ROW0/A2)
R1: A1.2, LED1.A10 (A), U1.P$24 (ROW1/A1)
R2: A0.2, LED1.A13 (A), U1.P$23 (ROW2/A0)
R3: LED1.A6 (A), SW1.A6, U1.P$22 (ROW3/K1)
R4: D5.C, D12.C, LED1.A1 (A), LED1.A5 (A), U1.P$21 (ROW4/K2)
R5: D8.C, D9.C, LED1.A2 (A), U1.P$20 (ROW5/K3)
R6: LED1.A12 (A), SW1.A12, U1.P$19 (ROW6/K4)
R7: LED1.A3 (A), SW1.A3, U1.P$18 (ROW7/K5)
R8: LED1.A8 (A), SW1.A8, U1.P$17 (ROW8/K6)
R9: LED1.A7 (A), SW1.A7, U1.P$16 (ROW9/K7)
R10: LED1.A4 (A), SW1.A4, U1.P$15 (ROW10/K8)
R11: D6.C, D7.C, LED1.A11 (A), U1.P$14 (ROW11/K9)
R12: D10.C, D11.C, LED1.A14 (A), U1.P$13 (ROW12/K10)
R13: LED1.A15 (A), SW1.A15, U1.P$12 (ROW13/K11)
R14: LED1.A16 (A), SW1.A16, U1.P$11 (ROW14/K12)
SCL: JP1.4, JP2.4, JP3.4, JP4.4, R1.1, U1.P$26 (SCL)
SDA: JP1.5, JP2.5, JP3.5, JP4.5, R2.2, U1.P$27 (SDA)
VCC: C1.2, C2.2, C3.2, C4.2, C5.2, JP1.2, JP2.2, JP3.2, JP4.2, R1.2, R2.1, U1.P$28 (VDD)

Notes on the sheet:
Adafruit Trellis 4x4 PCB w/3mm LED HT16K33 LED/Keypad I2C Driver GNU Public License v2

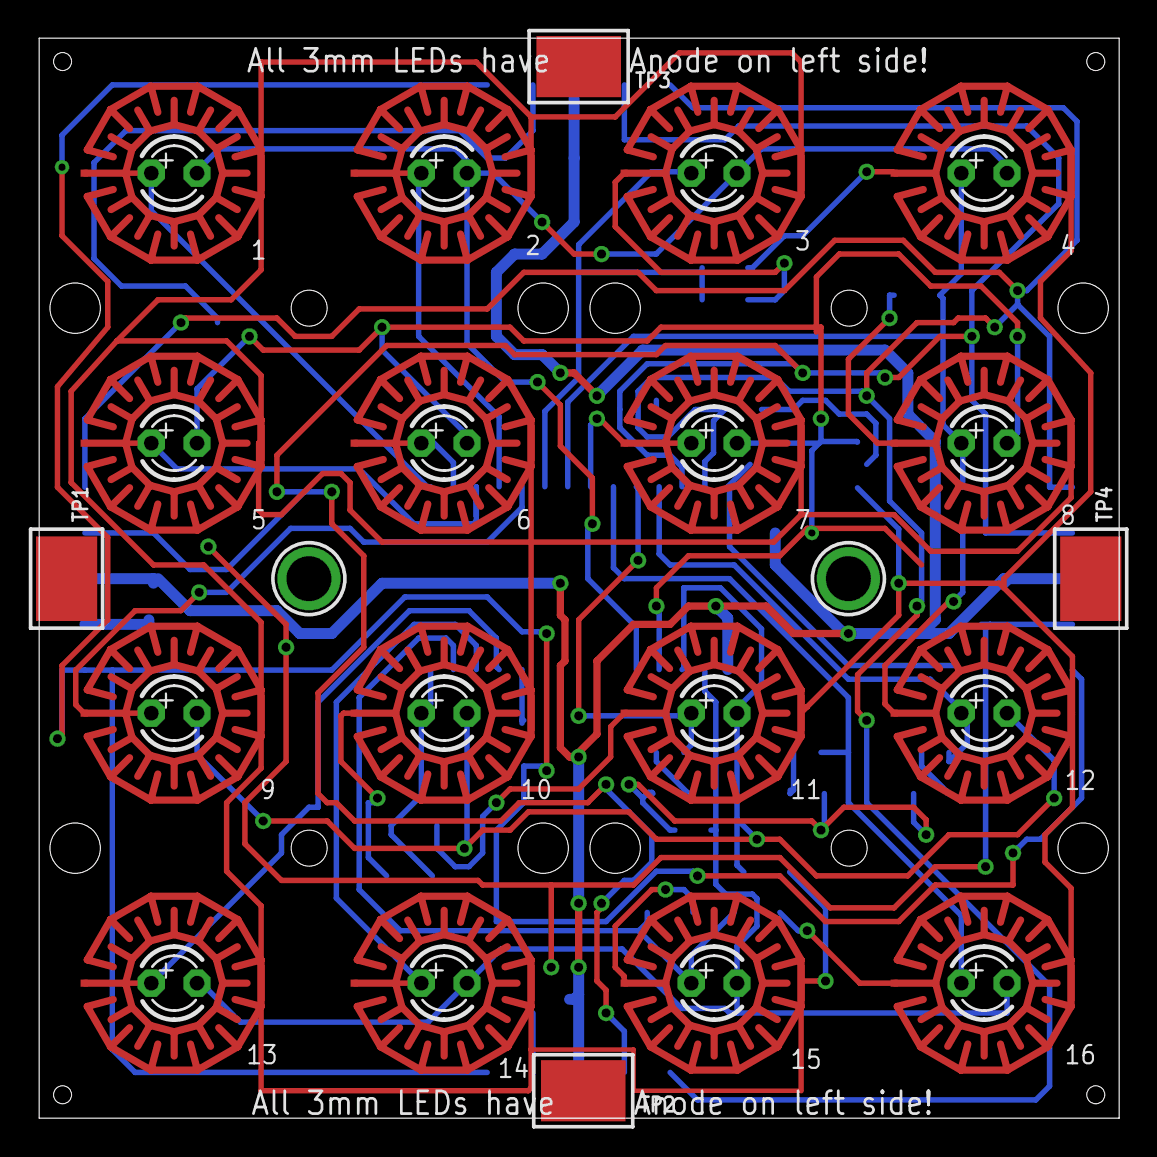
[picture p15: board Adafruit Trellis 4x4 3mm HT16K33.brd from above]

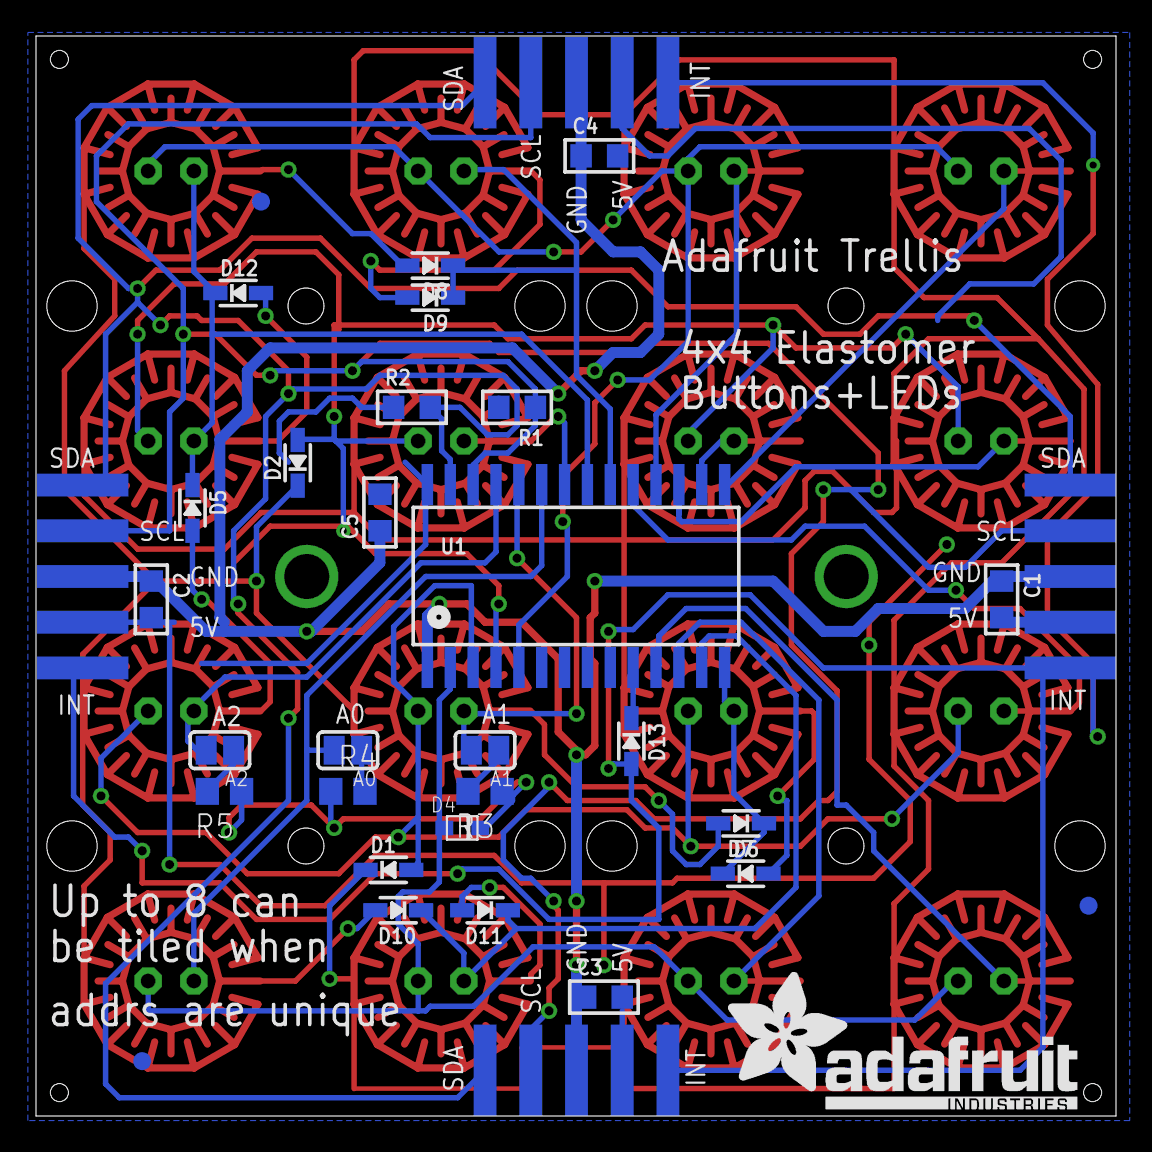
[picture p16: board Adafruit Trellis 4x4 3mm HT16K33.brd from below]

Board: 2 copper layers, 60.0 x 60.0 mm, 42 parts (34 on the bottom side), 39 nets.

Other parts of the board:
U$3: ADAFRUIT_TEXT_20MM

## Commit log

2020-05-14 init repo
    [ratatech_echo.dsn, ratatech_echo.kicad_pcb, ratatech_echo.sch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]
2020-05-20 Routing full done first try
    [Adafruit Trellis 3mm.stl, Adafruit Trellis 3mm.stp, Adafruit Trellis 4x4 3mm HT16K33.brd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]
2020-05-21 Top pcb img changes1
2020-05-22 Added small spring reverb description
2020-06-07 Component rearrengement
    [ratatech_echo.kicad_pcb]
2020-06-09 Autorouting done
    [ratatech_echo.dsn, ratatech_echo.kicad_pcb, ratatech_echo.sch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]
2020-06-09 PCB done v1.0. Generated gerbers for fab
    [ratatech_echo-B_Cu.gbl, ratatech_echo-B_Mask.gbs, ratatech_echo-B_Paste.gbp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]
2020-06-11 Added mouser part numbers
    [ratatech_echo.csv, ratatech_echo.sch]
2020-06-14 Finished BOM with mouser part numbers
    [ratatech_echo.csv, ratatech_echo.sch]

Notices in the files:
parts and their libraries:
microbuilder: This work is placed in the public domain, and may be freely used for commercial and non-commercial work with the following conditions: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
